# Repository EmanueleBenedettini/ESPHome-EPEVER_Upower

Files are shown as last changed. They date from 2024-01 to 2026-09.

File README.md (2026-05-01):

# ESPHome-EPEVER_Upower

Code and instructions for the integration of EPEVER Upower inverters in Home Assistant.

## Configuration

In `upower.yaml`, update the following values to match your setup:

- **Line 19**: `YOURAPIENCRYPTIONKEY` - Your API encryption key
- **Line 22**: `YOUROTAPASSWORD` - Your OTA password
- **Line 31**: `YOURPASSWORD` - Your device password

## Firmware Size

The code is optimized to fit on an ESP01_1M module while maintaining OTA update capability.

## Board Design

A custom PCB design is included (created with Eagle). To manufacture your board:

1. Go to a site like [jlcpcb.com](https://jlcpcb.com)
2. Upload the `Gerber.zip` file

### Components to Solder

| Designator | Value | Package |
|---|---|---|
| R5, R6 | 3.3kΩ | M1206 |
| R1, R2 | 10kΩ | M1206 |
| R4 | 120Ω | M1206 |
| U2 | AMS1117-3.3 | SOT229P700X180-4N |
| Q1 | 2N7002 N-Channel MOSFET | SOT23 |
| IC1 | MAX485 | SO08 |
| C1, C2 | 100µF | 6mm diameter |

### Notes

- **U1** (ESP01): In most cases, this does not need to be soldered. It should fit snugly in the socket.

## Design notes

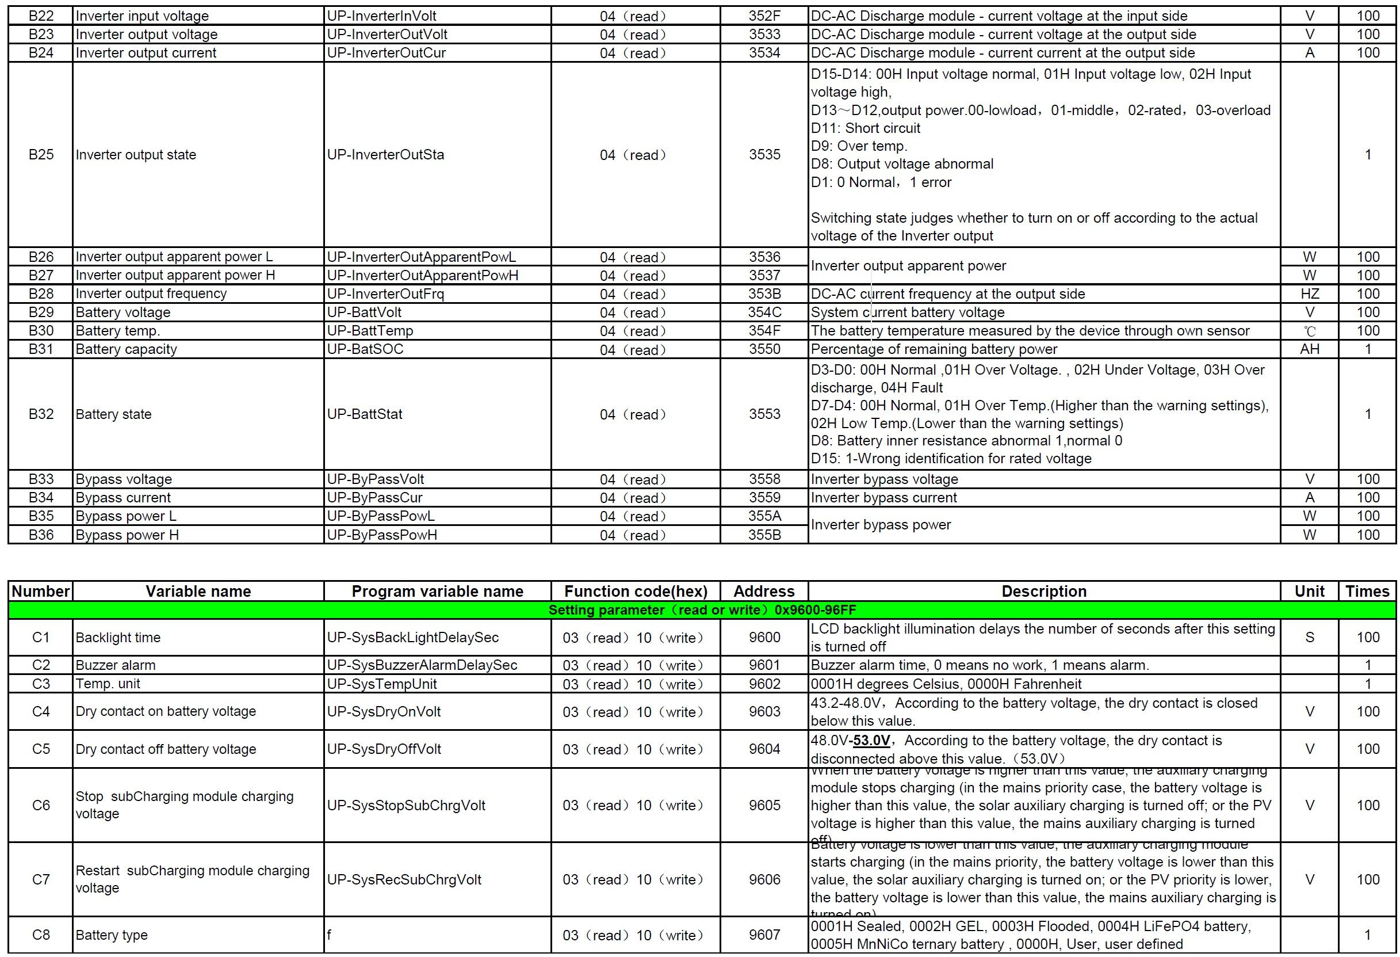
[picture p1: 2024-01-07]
Modbus registers/1667315165172-upower2.jpg

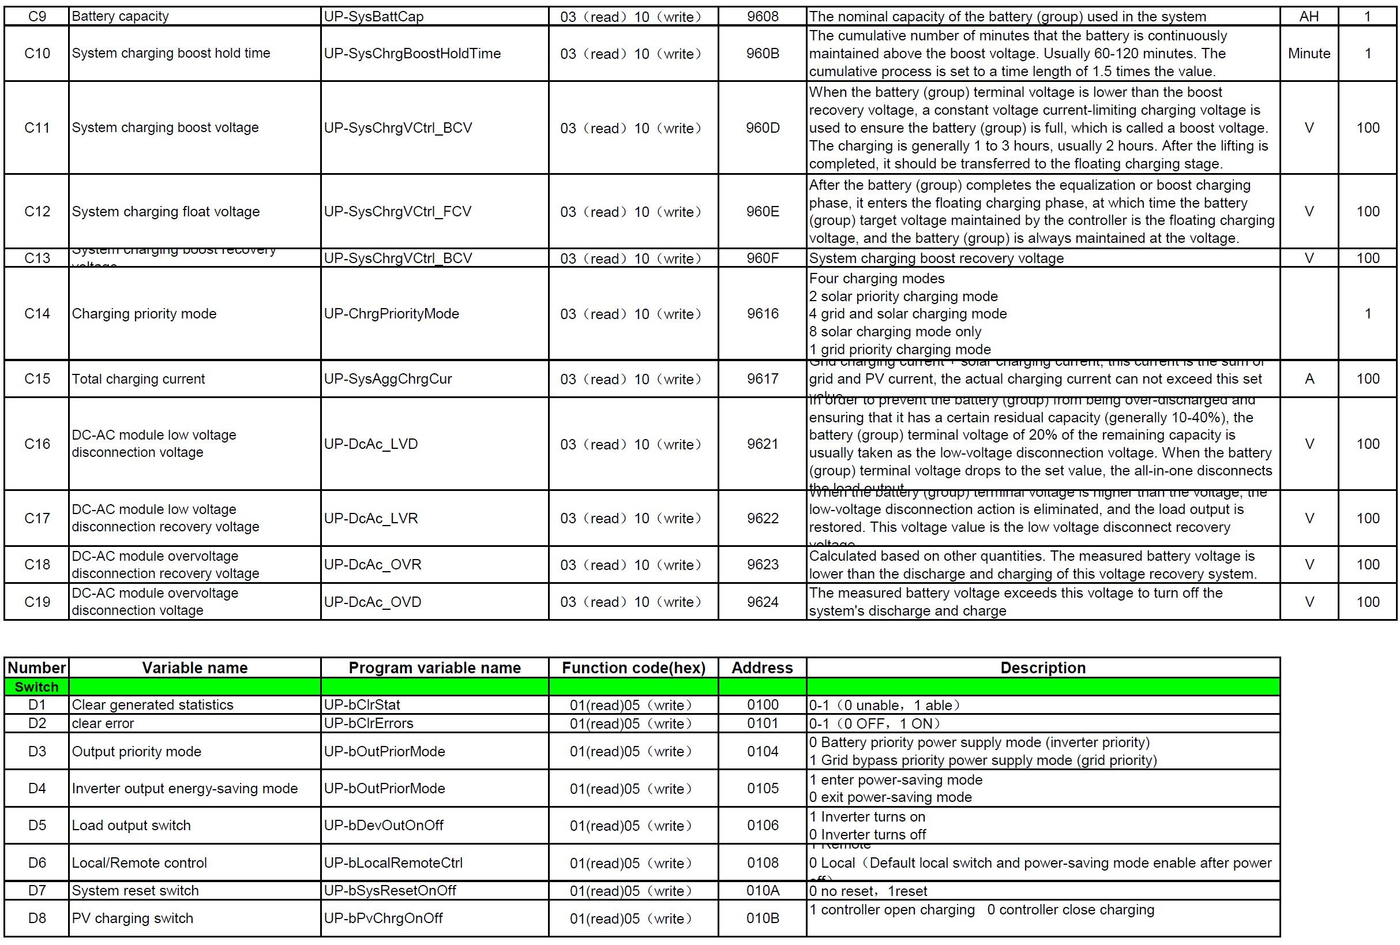
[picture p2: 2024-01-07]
Modbus registers/1667315172331-upower3.jpg

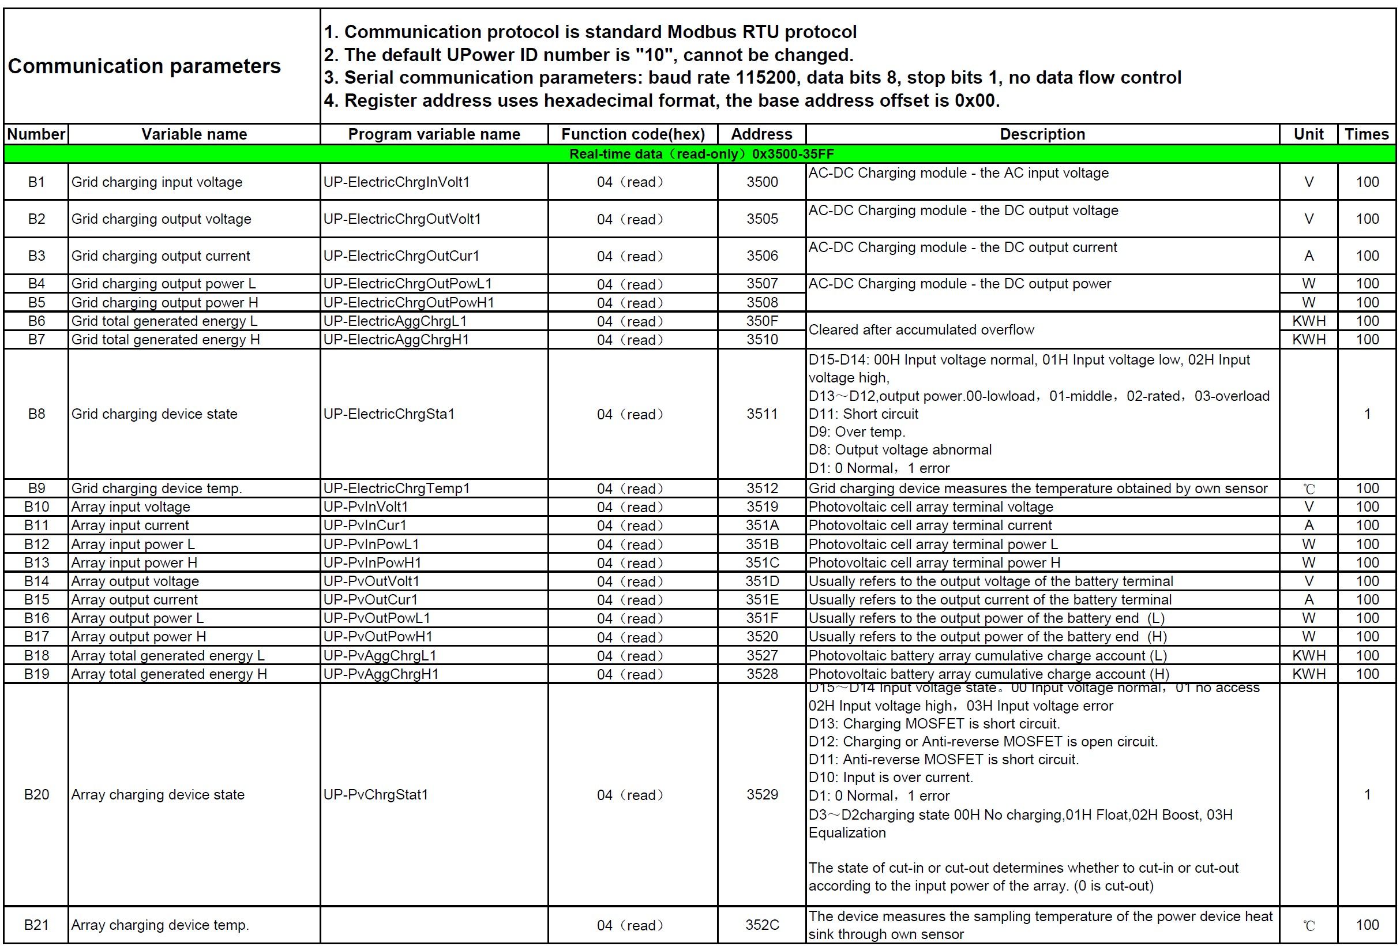
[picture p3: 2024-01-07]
Modbus registers/1667315153479-upower1.jpg

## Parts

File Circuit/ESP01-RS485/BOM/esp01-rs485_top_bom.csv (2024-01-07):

Comment | Designator | Footprint | LCSC Part #
3.3k | R5 R6 | M1206
10k | R1 R2 | M1206
120 | R4 | M1206
AMS1117-3.3 | U2 | SOT229P700X180-4N
BSS123 | Q1 | SOT23
MAX3468CSA | IC1 | SO08

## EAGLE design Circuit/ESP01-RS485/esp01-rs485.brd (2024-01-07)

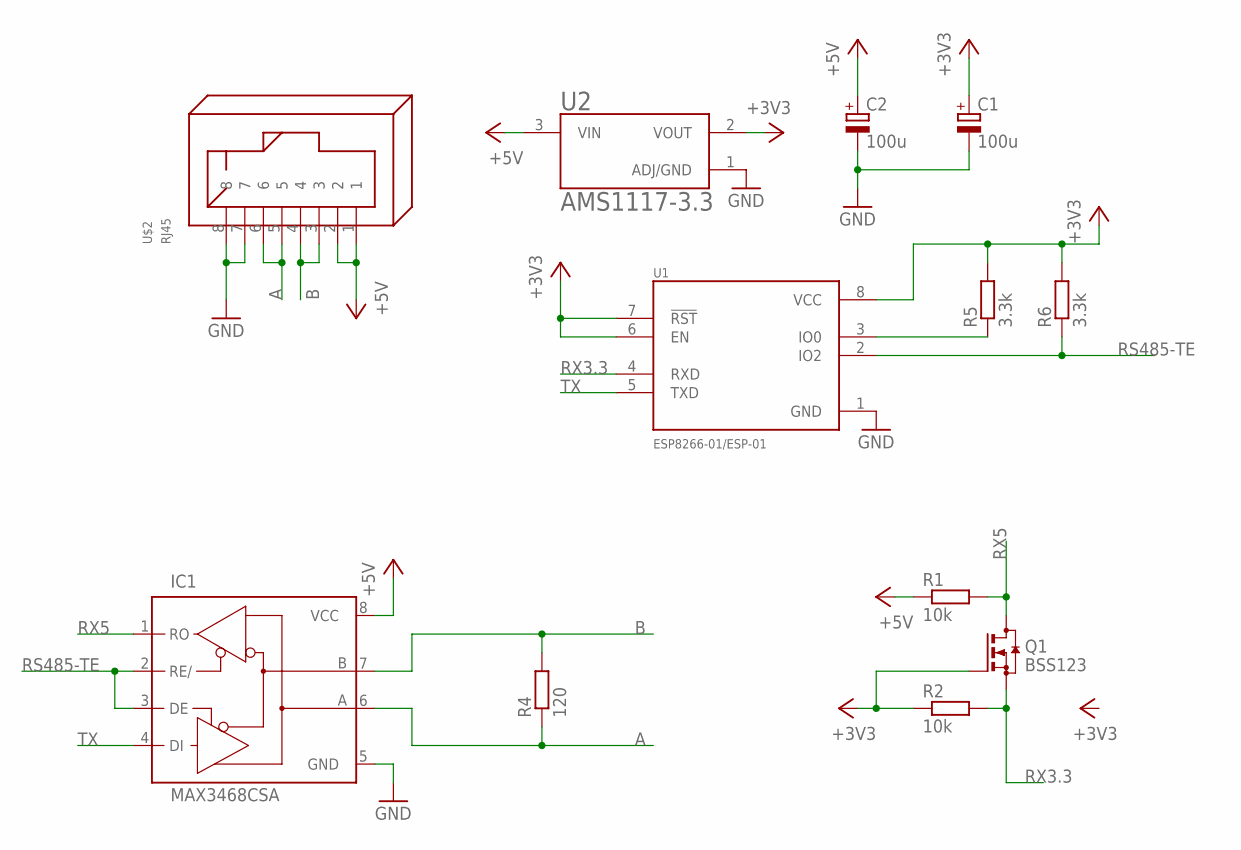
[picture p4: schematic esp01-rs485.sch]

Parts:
C1, C2: 100u; E2,5-6
IC1: MAX3468CSA; SO08
Q1: BSS123; SOT23
R1, R2: 10k; M1206
R4: 120; M1206
R5, R6: 3.3k; M1206
U1: ESP8266-01/ESP-01; XCVR_ESP8266-01/ESP-01
U2: AMS1117-3.3; SOT229P700X180-4N
U$2: RJ45

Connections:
+3V3: C1.+, Q1.1 (G), R2.1, R5.2, R6.2, U1.6 (EN), U1.7 (!RST), U1.8 (VCC), U2.2 (VOUT)
+5V: C2.+, IC1.8 (VCC), R1.1, U2.3 (VIN), U$2.1, U$2.2
A: IC1.6 (A), R4.1, U$2.5, U$2.6
B: IC1.7 (B), R4.2, U$2.3, U$2.4
GND: C1.-, C2.-, IC1.5 (GND), U1.1 (GND), U2.1 (ADJ/GND), U$2.7, U$2.8
unnamed: R5.1, U1.3 (IO0)
RS485-TE: IC1.2 (RE/), IC1.3 (DE), R6.1, U1.2 (IO2)
RX3.3: Q1.2 (S), R2.2, U1.4 (RXD)
RX5: IC1.1 (RO), Q1.3 (D), R1.2
TX: IC1.4 (DI), U1.5 (TXD)

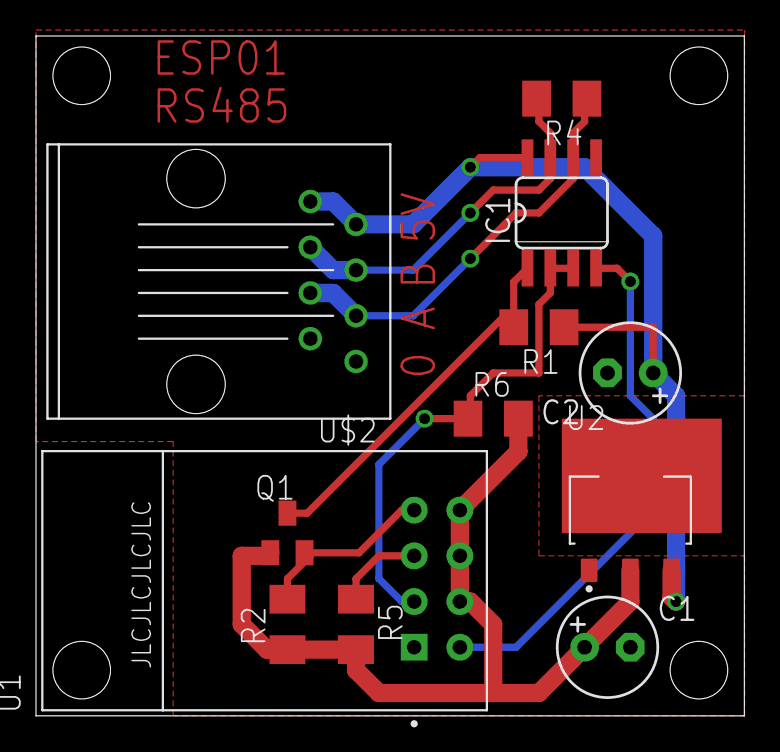
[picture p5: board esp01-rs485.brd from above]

Board: 2 copper layers, 39.4 x 37.8 mm, 12 parts (0 on the bottom side), 10 nets.

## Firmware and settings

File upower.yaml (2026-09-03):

substitutions:
  updates: 60s

esphome:
  name: upower
  friendly_name: Upower

esp8266:
  board: esp01_1m

# Enable logging
logger:
  level: VERBOSE #INFO
  baud_rate: 0

# Enable Home Assistant API
api:
  encryption:
    key: "YOURAPIENCRIPTIONKEY"

ota:
  password: "YOUROTAPASSWORD"

wifi:
  ssid: !secret wifi_ssid
  password: !secret wifi_password

  # Enable fallback hotspot (captive portal) in case wifi connection fails
  ap:
    ssid: "Upower Fallback Hotspot"
    password: "YOURPASSWORD"

captive_portal:
    
uart:
  id: mod_bus
  tx_pin: 1
  rx_pin: 3
  baud_rate: 115200
  stop_bits: 1

modbus:
  flow_control_pin: 2
  send_wait_time: 5000ms
  id: modbus1

modbus_controller:
  - id: epever
    ## the Modbus device addr
    address: 0xA
    modbus_id: modbus1
    setup_priority: -10
    command_throttle: 500ms
    update_interval: ${updates}

binary_sensor:
- platform: modbus_controller
  modbus_controller_id: epever
  id: inverter_bypass
  name: "Inverter Bypass"
  # 0:NoBypass, 1:Bypass 
  address: 0x2100
  register_type: discrete_input

- platform: modbus_controller
  modbus_controller_id: epever
  id: day_sensor
  name: "Day sensor"
  # 0:Night, 1:Day 
  address: 0x2101
  register_type: discrete_input

switch:
  - platform: modbus_controller
    modbus_controller_id: epever
    id: grid_priority
    register_type: coil
    address: 0x0104
    name: "Grid priority"
    bitmask: 1

  - platform: modbus_controller
    modbus_controller_id: epever
    id: inverter_energy_saving
    register_type: coil
    address: 0x0105
    name: "Inverter energy saving"
    bitmask: 1

  - platform: modbus_controller
    modbus_controller_id: epever
    id: inverter
    register_type: coil
    address: 0x0106
    name: "Inverter"
    bitmask: 1

  - platform: modbus_controller
    modbus_controller_id: epever
    id: grid_charging
    register_type: coil
    address: 0x010C
    name: "Grid charging"
    bitmask: 1

number:
  - platform: modbus_controller
    modbus_controller_id: epever
    id: max_battery_charging_current
    name: "Max battery charging current"
    address: 0x9617
    use_write_multiple: true
    register_type: holding
    value_type: U_WORD
    unit_of_measurement: A
    multiply: 100
    min_value: 15
    max_value: 60
    step: 0.1
    
select:
  - platform: modbus_controller
    modbus_controller_id: epever
    id: charge_from
    name: "Charge from"
    address: 0x9616
    use_write_multiple: true
    value_type: U_WORD
    optionsmap:
      "Solar": 8
      "Solar Priority": 2
      "Utility & Solar": 4
      "Utility": 1

sensor:
  - platform: wifi_signal
    name: "WiFi Signal"
    update_interval: ${updates}
    
  # Utility
  - platform: modbus_controller
    modbus_controller_id: epever
    id: grid_voltage
    name: "Grid Voltage"
    unit_of_measurement: V
    address: 0x3500
    register_type: read
    accuracy_decimals: 2
    filters:
      - multiply: 0.01      

  - platform: modbus_controller
    modbus_controller_id: epever
    id: grid_charger_current
    name: "Grid charger Current"
    unit_of_measurement: A
    address: 0x3506
    register_type: read
    accuracy_decimals: 2
    filters:
      - multiply: 0.01 

  - platform: modbus_controller
    modbus_controller_id: epever
    id: grid_charger_power_internal
    unit_of_measurement: W
    address: 0x3507
    register_type: read
    accuracy_decimals: 0
    filters:
      - multiply: 0.01
    on_raw_value:
      then:
        - lambda: |-
            id(grid_charger_power).publish_state(id(grid_charger_current).state * id(battery_voltage).state);

  - platform: template
    id: grid_charger_power
    name: "Grid charger Power"
    unit_of_measurement: W

  - platform: modbus_controller
    modbus_controller_id: epever
    id: grid_charger_temp
    name: "Grid charger temp"
    unit_of_measurement: "°C"
    address: 0x3512
    register_type: read
    filters:
      - multiply: 0.01
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
